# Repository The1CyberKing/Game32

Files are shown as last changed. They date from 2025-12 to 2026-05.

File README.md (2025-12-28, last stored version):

### The goal:

Show CSS 342 Knowledge with C++

Show new learning of ESP32 as a beginner.

Showcase skills of building firmware, not the games. Specifically the firmware to allows for Arduboy games to run on Game32 (why reinvent the wheel? Compare to How firmware is built to run windows. Allat stuff)

Since hardware selection is low risk, we started with a hardware first solution (Hardware first development). Finished the hardware before coding.

As lazy as it sounds I didnt want to open my phone when gaming, so esp32 was the way to go

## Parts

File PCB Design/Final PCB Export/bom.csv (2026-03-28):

Designator | Footprint | Quantity | Value | LCSC Part #
C1, C2, C3 | 0805 | 3 | 103p | C1710
R1, R2 | 0805 | 2 | 100k | C149504

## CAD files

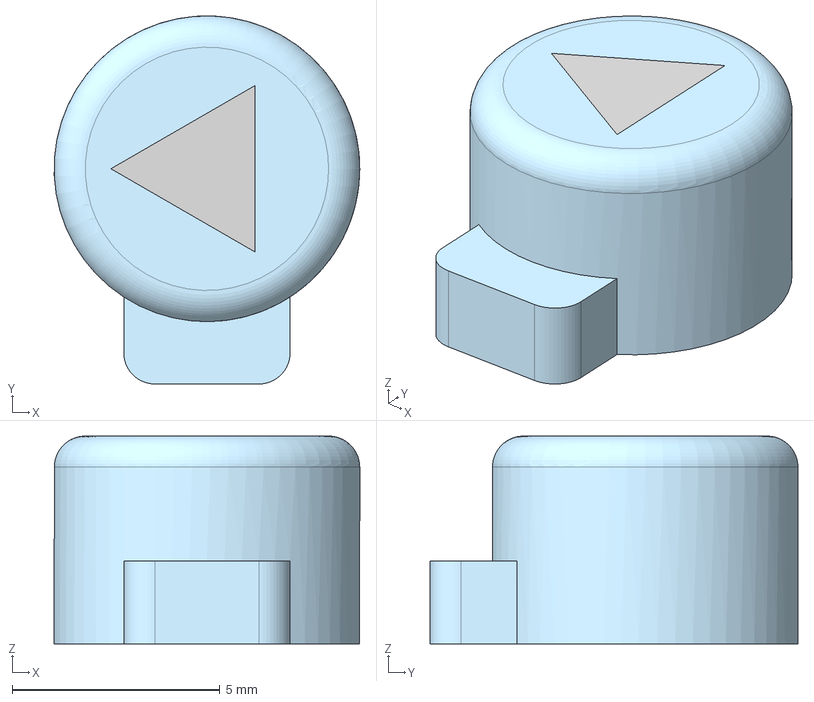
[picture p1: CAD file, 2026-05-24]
3D Models/First Print/Buttons/Left.step
7.35 x 8.85 x 5.00 mm

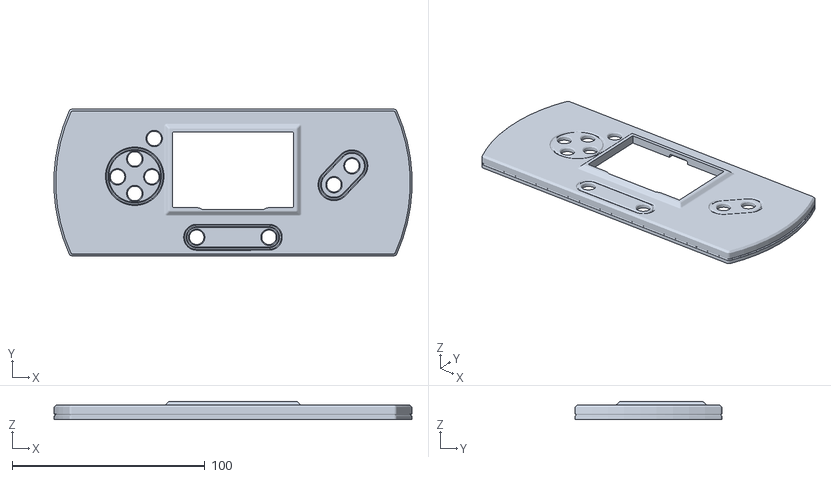
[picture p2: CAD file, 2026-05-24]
3D Models/First Print/Top Housing.stl
185.6 x 76.0 x 9.50

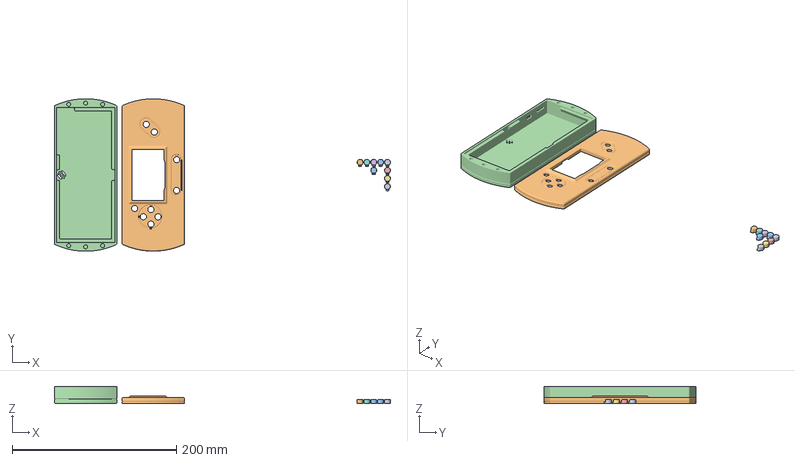
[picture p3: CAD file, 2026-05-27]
3D Models/Game32 Bambulab Print Files.3mf
409.6 x 185.8 x 21.0 mm
A.step
Top Housing.stl
B.step
Bottom Housing.step
Down.step
Left.step x 2
Power.step
Right.step x 2
Up.step

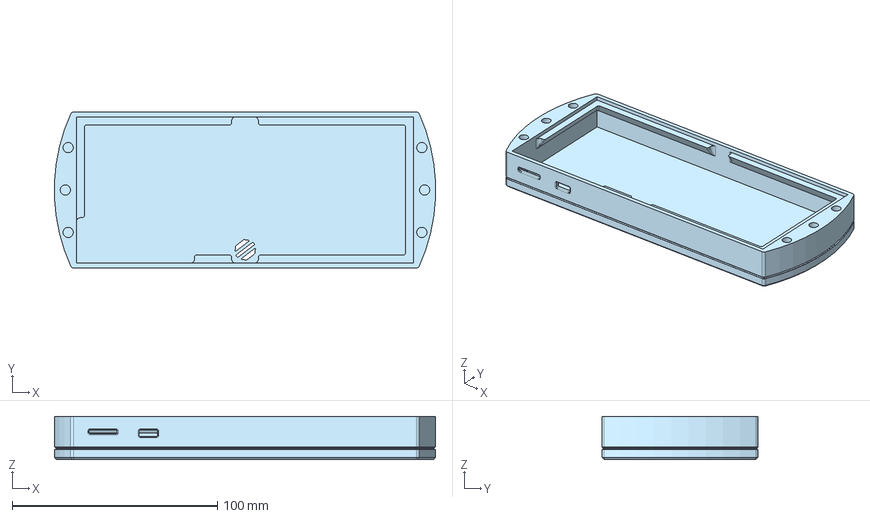
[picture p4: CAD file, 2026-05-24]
3D Models/First Print/Bottom Housing.step
185.6 x 76.0 x 21.0 mm

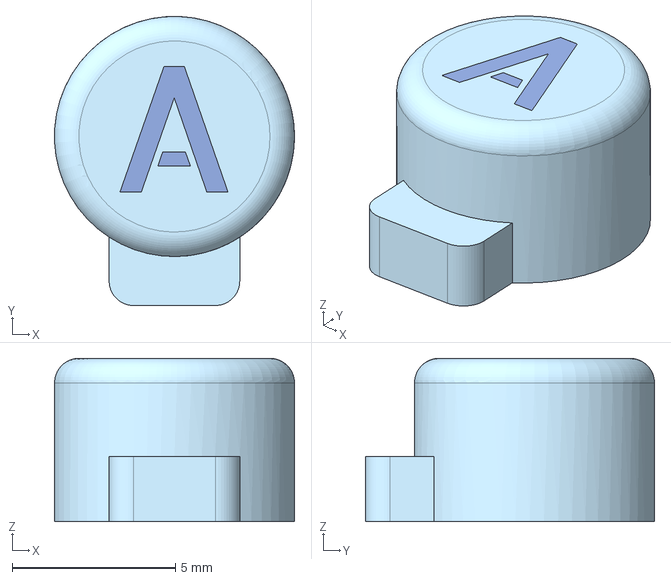
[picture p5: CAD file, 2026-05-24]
3D Models/First Print/Buttons/A.step
7.35 x 8.85 x 5.00 mm

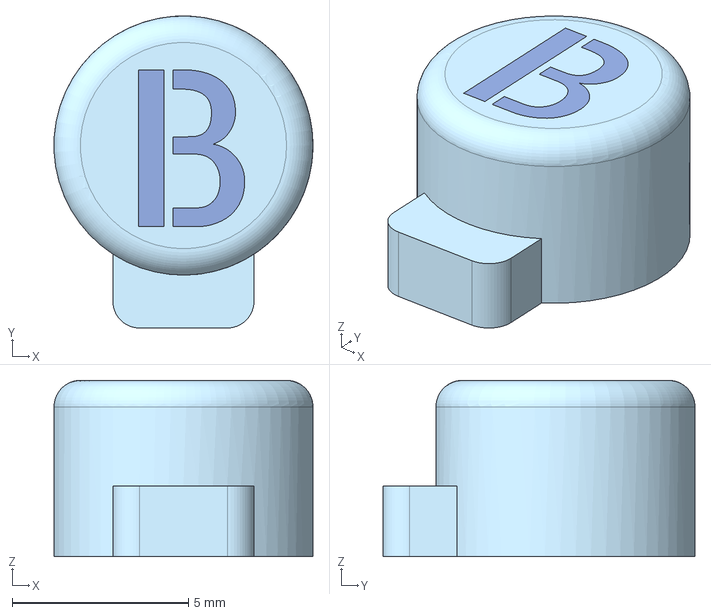
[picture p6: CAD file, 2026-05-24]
3D Models/First Print/Buttons/B.step
7.35 x 8.85 x 5.00 mm

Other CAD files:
3D Models/First Print/Buttons/Up.step
3D Models/First Print/Buttons/Down.step
3D Models/First Print/Buttons/Right.step
3D Models/First Print/Buttons/Power.step

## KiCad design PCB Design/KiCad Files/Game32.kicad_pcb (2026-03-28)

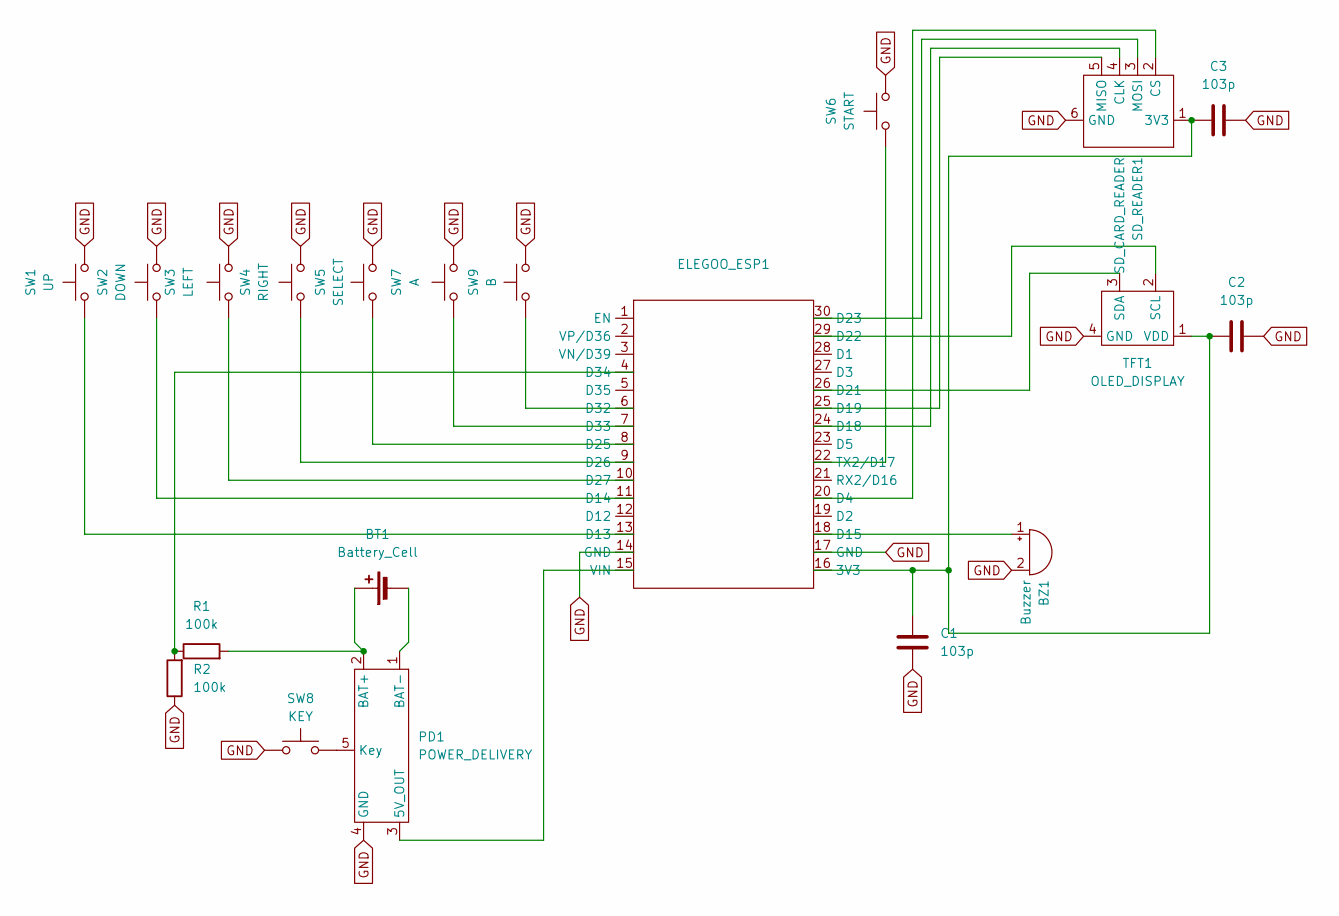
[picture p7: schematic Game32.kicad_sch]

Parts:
BT1: Battery_Cell; 2_Battery_Pads
BZ1: Buzzer; Buzzer_TH_7mm_2Pin
C1, C2, C3: 103p; C_0805_2012Metric; LCSC C1710
ELEGOO_ESP1: ELEGOO ESP32 DevKit Type C V1
PD1: POWER_DELIVERY; 5V_Boost_Converter
R1, R2: 100k; R_0805_2012Metric; LCSC C149504
SD_READER1: SD_CARD_READER; SD_Card_Reader_Custom
SW1: UP; SW_Tact_2Pin_6x6x5mm
SW2: DOWN; SW_Tact_2Pin_6x6x5mm
SW3: LEFT; SW_Tact_2Pin_6x6x5mm
SW4: RIGHT; SW_Tact_2Pin_6x6x5mm
SW5: SELECT; SW_Tact_2Pin_6x6x5mm
SW6: START; SW_Tact_2Pin_6x6x5mm
SW7: A; SW_Tact_2Pin_6x6x5mm
SW8: KEY; SW_Tact_2Pin_6x6x5mm
SW9: B; SW_Tact_2Pin_6x6x5mm
TFT1: OLED_DISPLAY; YELUFT-SSD1309-2.42in

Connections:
GND: BZ1.2 (-), C1.1, C2.2, C3.2, ELEGOO_ESP1.14 (GND), ELEGOO_ESP1.17 (GND), PD1.4 (GND), R2.1, SD_READER1.6 (GND), SW1.2, SW2.2, SW3.2, SW4.2, SW5.2, SW6.2, SW7.2, SW8.1, SW9.2, TFT1.4 (GND)
unnamed: BT1.1 (+), PD1.2 (BAT+), R1.2
unnamed: BT1.2 (-), PD1.1 (BAT-)
unnamed: BZ1.1 (+), ELEGOO_ESP1.18 (D15)
unnamed: C1.2, C2.1, C3.1, ELEGOO_ESP1.16 (3V3), SD_READER1.1 (3V3), TFT1.1 (VDD)
unnamed: ELEGOO_ESP1.20 (D4), SD_READER1.2 (CS)
unnamed: ELEGOO_ESP1.13 (D13), SW1.1
unnamed: ELEGOO_ESP1.11 (D14), SW2.1
unnamed: ELEGOO_ESP1.24 (D18), SD_READER1.4 (CLK)
unnamed: ELEGOO_ESP1.25 (D19), SD_READER1.5 (MISO)
unnamed: ELEGOO_ESP1.26 (D21), TFT1.3 (SDA)
unnamed: ELEGOO_ESP1.29 (D22), TFT1.2 (SCL)
unnamed: ELEGOO_ESP1.30 (D23), SD_READER1.3 (MOSI)
unnamed: ELEGOO_ESP1.8 (D25), SW5.1
unnamed: ELEGOO_ESP1.9 (D26), SW4.1
unnamed: ELEGOO_ESP1.10 (D27), SW3.1
unnamed: ELEGOO_ESP1.6 (D32), SW9.1
unnamed: ELEGOO_ESP1.7 (D33), SW7.1
unnamed: ELEGOO_ESP1.4 (D34), R1.1, R2.2
unnamed: ELEGOO_ESP1.22 (TX2/D17), SW6.1
unnamed: ELEGOO_ESP1.15 (VIN), PD1.3 (5V_OUT)
unnamed: PD1.5 (Key), SW8.2

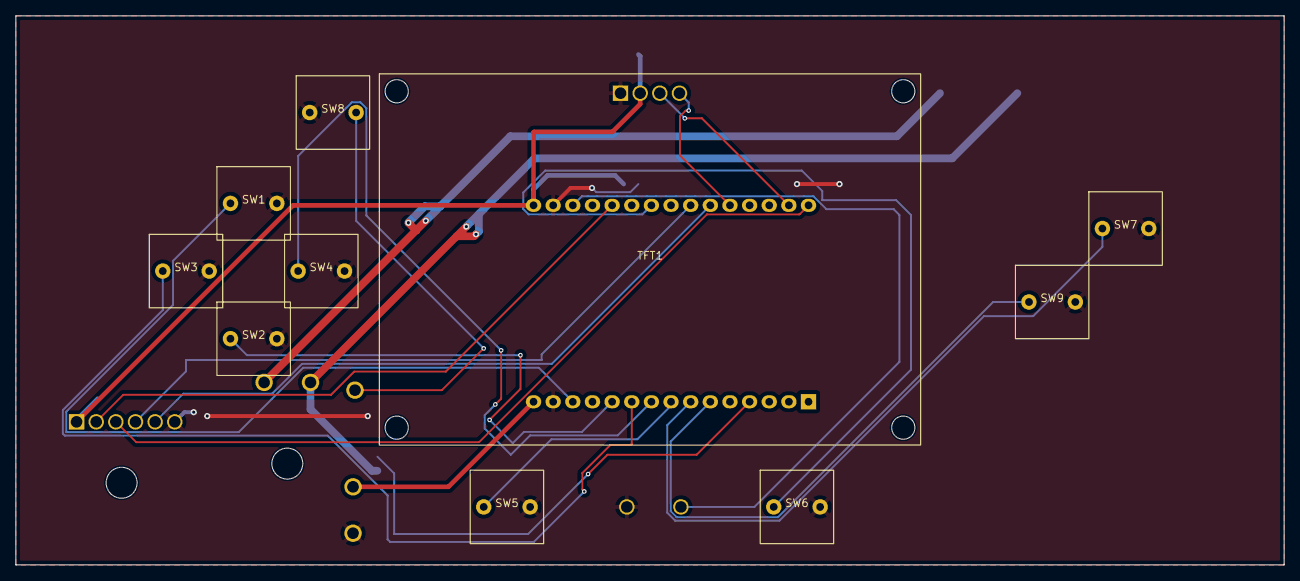
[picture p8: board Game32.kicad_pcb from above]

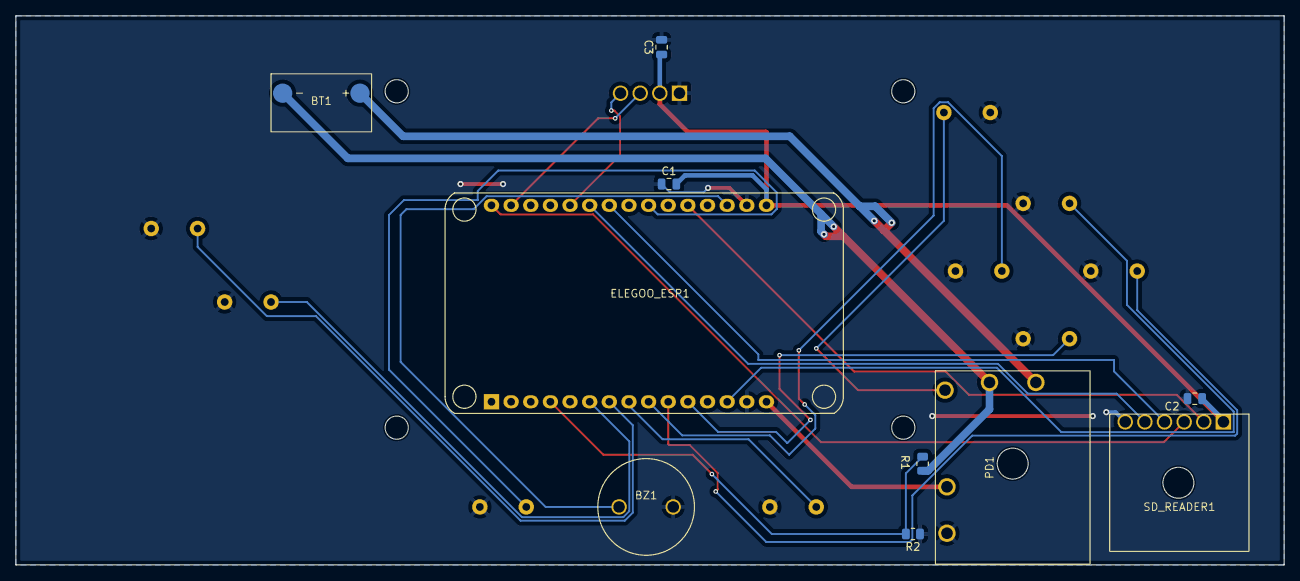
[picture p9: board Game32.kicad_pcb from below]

Board: 2 copper layers, 164.0 x 71.0 mm, 20 parts (10 on the bottom side), 22 nets.

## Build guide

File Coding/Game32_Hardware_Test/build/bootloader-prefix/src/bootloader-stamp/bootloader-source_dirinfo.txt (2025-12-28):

# This is a generated file and its contents are an internal implementation detail.
# The download step will be re-executed if anything in this file changes.
# No other meaning or use of this file is supported.

method=source_dir
command=
source_dir=E:/Applications/ESP32/esp-idf/components/bootloader/subproject
work_dir=

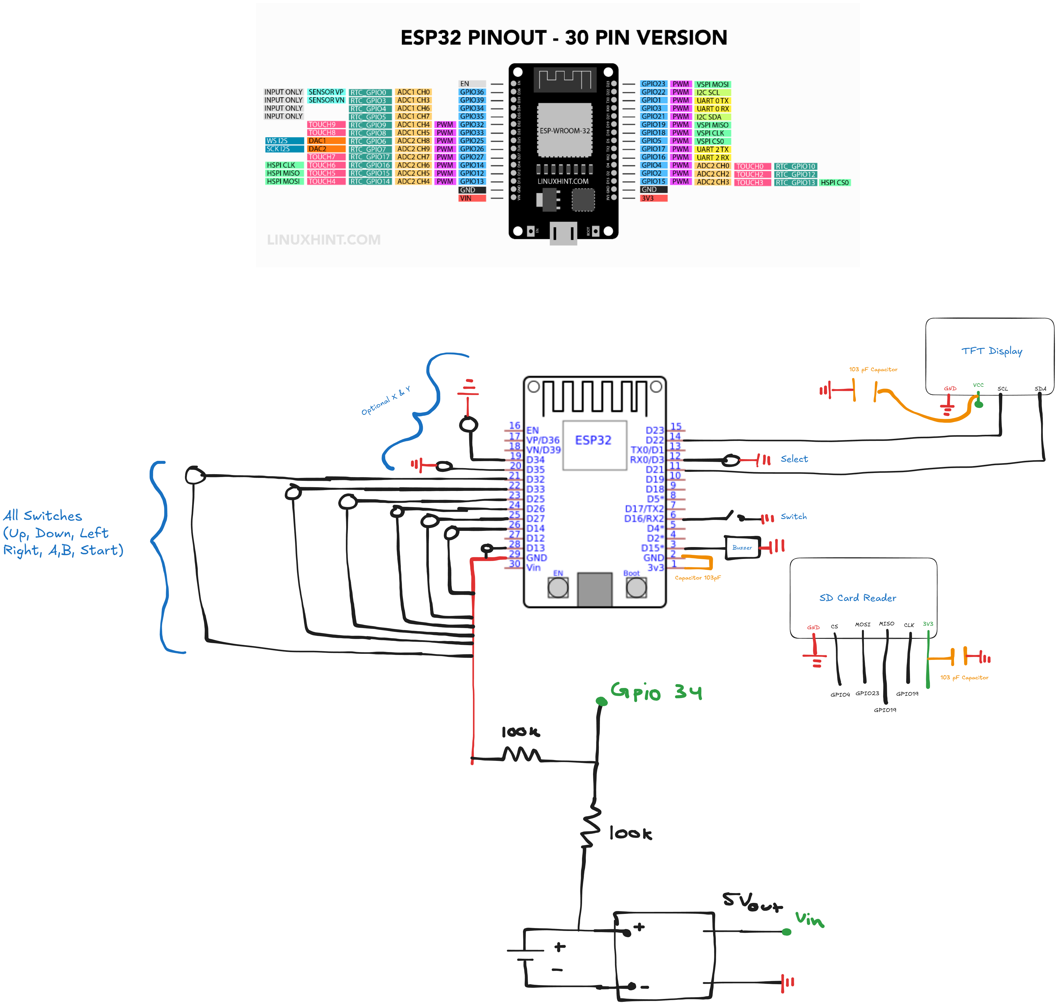
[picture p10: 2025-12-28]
Wiring/Wiring Diagram V1.png

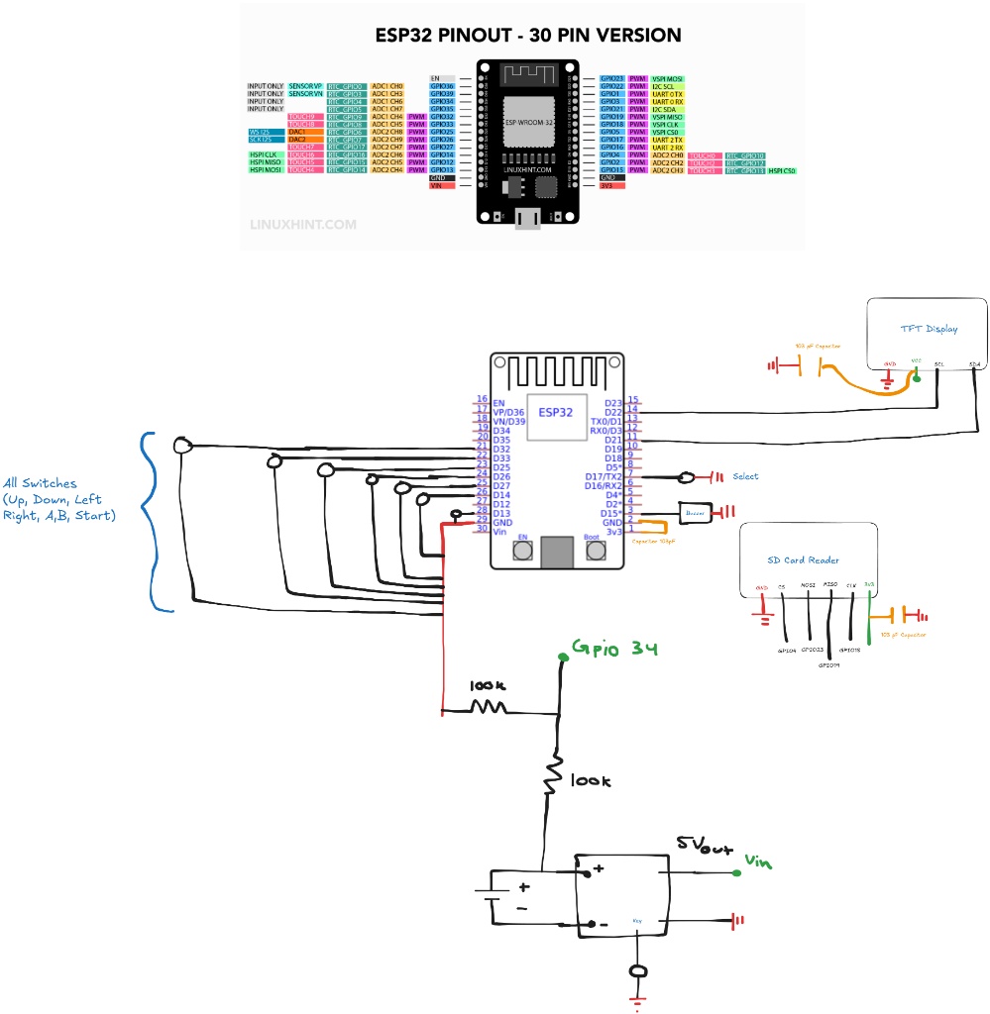
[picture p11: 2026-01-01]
Wiring/Wiring Diagram V2.jpg

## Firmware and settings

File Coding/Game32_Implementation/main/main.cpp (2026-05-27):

#include <freertos/FreeRTOS.h>
#include <freertos/task.h>
#include <freertos/semphr.h>
#include <esp_log.h>

#include "types.h"
#include "config.h"

#include "BatteryManager.h"
#include "PowerManager.h"
#include "DisplayManager.h"
#include "InputManager.h"

#include "StateManager.h"
#include "States/StartupState.h"

static const char* TAG = "Game32_Kernel";

// Global Context
SystemContext sysContext;
SemaphoreHandle_t g_i2cMutex = NULL;

// ===== CORE 0: SYSTEM HEALTH DAEMONS =====
void core0_system_services_task(void *pvParameters) {
    BatteryManager::getInstance().initialize();
    PowerManager::getInstance().initialize();

    while (1) {
        BatteryManager::getInstance().updateService();
        PowerManager::getInstance().executeAdaptiveKeepalive();
        vTaskDelay(pdMS_TO_TICKS(100));
    }
}

// ===== CORE 1: MAIN APPLICATION ENGINE =====
void core1_graphics_engine_task(void *pvParameters) {
    DisplayManager::getInstance().initialize();
    InputManager::getInstance().initialize();

    StateManager::getInstance().changeState(&StartupState::getInstance());

    // FIX: Deterministic frame pacing
    TickType_t lastWakeTime = xTaskGetTickCount();
    const TickType_t frameDelay = pdMS_TO_TICKS(33); 

    while (1) {
        InputManager::getInstance().update(); // Poll & Debounce
        StateManager::getInstance().update();
        StateManager::getInstance().draw();
        DisplayManager::getInstance().renderPipelinePush();

        // Pauses the task strictly for the exact remainder of the 33ms window
        vTaskDelayUntil(&lastWakeTime, frameDelay);
        // Fallback: If we missed the deadline, vTaskDelayUntil returns immediately.
        // We MUST force a yield here so the Idle task can feed the watchdog on Core 1.
        vTaskDelay(1); 
    }
}

// ===== ENTRY POINT =====
extern "C" void app_main(void) {
    ESP_LOGI(TAG, "Initializing Game32 Kernel...");

    // FIX: Hardware Mutex MUST be created before any tasks start using the bus
    g_i2cMutex = xSemaphoreCreateMutex();
    if (g_i2cMutex == NULL) {
        ESP_LOGE(TAG, "FATAL: Failed to create I2C Mutex.");
        return;
    }

    xTaskCreatePinnedToCore(
        core0_system_services_task, "SystemServices", DEFAULTS_STACK_SIZE_CORE0, NULL, 2, NULL, 0
    );

    xTaskCreatePinnedToCore(
        core1_graphics_engine_task, "GraphicsEngine", GRAPHICS_STACK_SIZE_CORE1, NULL, 5, NULL, 1
    );
}

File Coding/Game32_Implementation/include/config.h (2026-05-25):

#ifndef GAME32_CONFIG_H
#define GAME32_CONFIG_H

#include <stdint.h>
#include <driver/i2c.h>

// I2C Bus Configuration
#define I2C_MASTER_NUM           I2C_NUM_0
constexpr uint32_t I2C_FREQ_HZ   = 400000;
constexpr uint8_t  SSD1306_I2C_ADDR = 0x3C;

// Power Management Configuration
constexpr uint32_t PIXEL_SAFE_THRESHOLD  = 4000;
constexpr uint32_t PIXEL_MIN_CRITICAL    = 1000;
constexpr uint32_t IDLE_TIMEOUT_MS       = 10000;

// Battery Filter Constants
constexpr uint8_t  BATTERY_SAMPLE_COUNT  = 30;
constexpr uint8_t  BATTERY_OUTLIER_DROP  = 5;

// FreeRTOS Task Allocations
constexpr uint32_t DEFAULTS_STACK_SIZE_CORE0 = 4096;
constexpr uint32_t GRAPHICS_STACK_SIZE_CORE1 = 8192;

// File System Path Conventions
#define SD_SYS_DIR   "/sd/sys"
#define SD_GAMES_DIR "/sd/games"
#define SD_SAVES_DIR "/sd/saves"
#define SD_ASSET_DIR "/sd/assets"

#endif // GAME32_CONFIG_H

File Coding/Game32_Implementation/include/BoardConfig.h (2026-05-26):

#pragma once

// ==========================================
// Game32 Hardware Configuration
// ==========================================

// --- Feature Flags ---
#define GAME32_HAS_SD_CARD true
#define GAME32_HAS_WIFI true
#define GAME32_HAS_AUDIO true
#define GAME32_DISPLAY_WIDTH 128
#define GAME32_DISPLAY_HEIGHT 64

// --- Status & Power ---
#define LED_GPIO 2
#define BAT_ADC_GPIO 34 // ADC1_CHANNEL_6

// --- Input Buttons ---
#define BTN_UP_GPIO     13 //13
#define BTN_DOWN_GPIO   14 //14
#define BTN_LEFT_GPIO   27 //27
#define BTN_RIGHT_GPIO  26 //26
#define BTN_A_GPIO      33 //33
#define BTN_B_GPIO      32 //32
#define BTN_START_GPIO  17 //17
#define BTN_SELECT_GPIO 25 //25

// --- Audio ---
#define BUZZER_GPIO 15

// --- SD Card SPI Pins ---
#define SD_MOSI_GPIO 23
#define SD_MISO_GPIO 19
#define SD_CLK_GPIO  18
#define SD_CS_GPIO   4

// --- OLED I2C Pins ---
#define TFT_SDA_GPIO 21
#define TFT_SCL_GPIO 22

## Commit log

2026-01-01 Updating the KiCad Files and Wiring Diagram Versions
    [Game32.kicad_pcb, Game32.kicad_sch]
2026-01-01 Updated PCB designs
    [Game32.kicad_pcb]
2026-03-28 PCB Completed
    [Game32.kicad_pcb, Game32.kicad_sch, bom.csv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]
2026-05-24 Version 1 of the 3D Models are Created, to be printed
    [A.step, B.step, Bottom Housing.step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]
2026-05-25 Working Boot Page, Display Manager Further Optimized. Flashed to ESP32, Real time Battery Sensing works.
2026-05-26 basic Menu Functionality
    [partitions.csv]
2026-05-27 Game UI Loads, but Low FPS. Pivoting to User PC Transcompiler
    [Game32 Bambulab Print Files.3mf]
2026-06-27 Clean slate: Wiped emulator core, restored config.h, migrated to ESP-IDF 6.0 APIs, deleted mock_env
    - Removed mock_env/ desktop test environment
    - Wiped EmulatorState to clean stub (kept IGameState interface)
    - Restored include/config.h from main branch
    - Migrated BatteryManager to modern esp_adc/adc_oneshot.h API
    - Fixed DisplayManager GPIO casts for ESP-IDF 6.0
    - Fixed SDManager struct initializer warnings
    - Reduced upload_speed to 115200 for stable flashing
    - Deleted old Python transpiler scripts
    - Successfully compiles and flashes on ESP-IDF 6.0.1
    [BoardConfig.h, config.h, main.cpp]
2026-07-28 Mass compilation (In-Progress)
    [partitions.csv]
